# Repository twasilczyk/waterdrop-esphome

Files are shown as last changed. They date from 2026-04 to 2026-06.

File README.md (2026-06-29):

# waterdrop-esphome

Smarten Waterdrop RO systems: a plug-in Wi-Fi add-on board to integrate with Home Assistant, read hidden diagnostic parameters, and work around refrigerator line limitations.

See the story: [Hacking a water filter through a 7-segment display](docs/story.md).

> [!WARNING]
> Use at your own risk. This is not a certified retail product, but an open-source hacking hobby project.

## Features

- Reads sensors exposed by original RO unit
  - Water TDS level
  - Individual filter state: total and remaining life plus derivative sensors (life percentage, filter health warning)
  - Pump state (idle, active, flushing)
  - Error codes
  - Ambient air temperature
  - Last filter change time
  - [Potentially more](docs/reverse-engineering.md), as about fourteen 16-bit fields are still not reverse-engineered
- Simulates faucet handle position (see [Refrigerator line workaround](#refrigerator-line-workaround))
- Switchable power supply to the main RO unit
- Emergency water shutoff with external latching solenoid valve

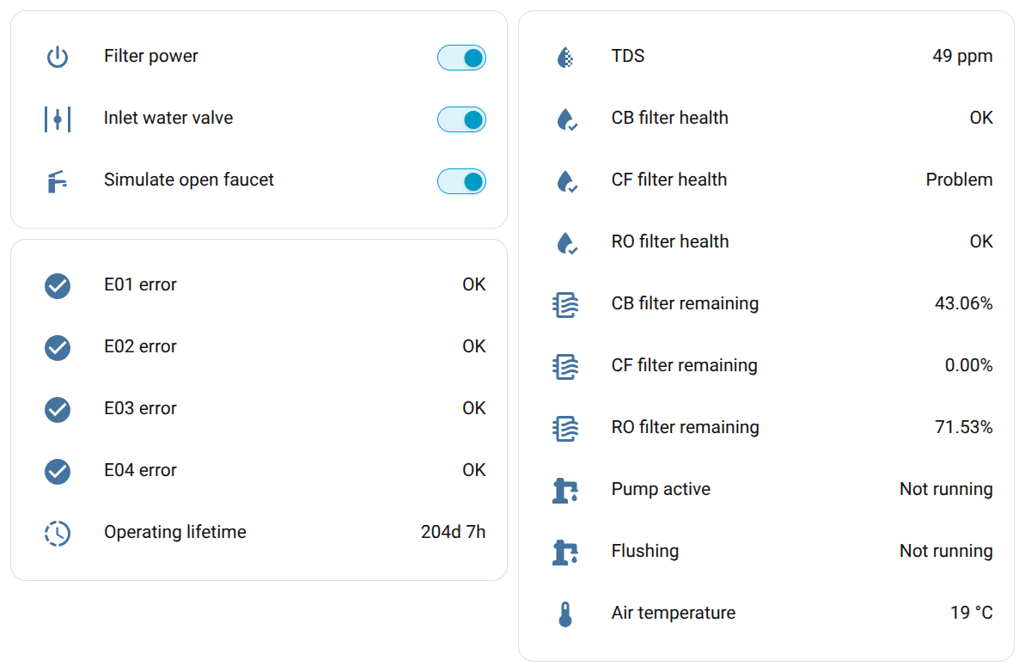
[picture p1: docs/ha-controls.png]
Screenshot of Home Assistant dashboard with controls and sensors


### Refrigerator line workaround

Waterdrop RO water filter systems don't play particularly well with refrigerator water lines. After dispensing water from the refrigerator, the RO unit tends to switch to an erratic flush mode: briefly flushing every 5 minutes. This continues until water is dispensed from the original Waterdrop smart faucet.

The simulated faucet handle feature works around this issue. If the RO unit performs this flush attempt while the faucet is reported open, it will start a proper flush cycle and switch back to the regular 12-hour flushing interval.

## Installing firmware

### ESPHome Builder

Best for long-term maintenance.

1. Define the following secrets (ESPHome Device Builder 🡒 three-dot menu 🡒 Secrets):
   - common_api_encryption_key
   - ota_password
   - wifi_ssid
   - wifi_password
2. Create device 🡒 Advanced set up options 🡒 Empty Configuration; paste the following:
   ```
   substitutions:
     branch: stable

   packages:
     waterdrop-esphome:
       url: https://github.com/twasilczyk/waterdrop-esphome
       ref: ${branch}
       files:
         - firmware/builder-package.yaml
   ```
3. Install over USB at first, then you can switch to OTA
4. If installing for the first time, don't forget to enable power to the RO system - it controlls both power supply and serial communication (with faucet as well as the main unit)

### Local environment

Best for development (from terminal or VSCode).

1. Set up ESPHome through the [pip method](https://esphome.io/guides/installing_esphome/#pip)
2. `cd path/to/repo`
3. `ln -s "$HOME/path/to/your/esphome-venv" .venv`
4. Create `secrets.yaml` one directory up from your repo root:
   ```
   wifi_ssid: "YourWiFi"
   wifi_password: "..."
   ota_password: "..."
   common_api_encryption_key: "..."
   ```

Then, you can build from terminal:
```
cd firmware
esphome run waterdrop-esphome.yaml
```

Or from VSCode:
1. Ctrl+Shift+P
2. `Tasks: Run Task`
3. `ESPHome: Run without debugging`

## Electronics

### Bill of materials

| Ref | Qty | Value | Product | Total cost [$] | Optional |
| --- | --- | --- | --- | --- | --- |
| C1  | 1 | 100µF/50V | 50YXJ100M8X11.5  | 0.43 | |
| C2  | 1 | 220µF/16V | 25YXJ220M6.3X11  | 0.31 | |
| C3  | 1 | 22nF | CL21B223KBANFNC  | 0.10 | |
| C4  | 1 | 100nF | CL21B104KBCNNNC  | 0.10 | |
| D1  | 1 | SMAJ30A | SMAJ30A | 0.22 | |
| D2  | 1 | B360A | B360A-13-F | 0.51 | |
| D3  | 1 | 1N4148 | 1N4148W-7-F | 0.17 | Yes (relay) |
| F1  | 1 | 500mA | 0PTF0078P + 0217.500MXP | 1.35 <!-- 0.78 + 0.57 --> | |
| J1  | 1 | DC5525 m  | PJ-002B | 0.66 | |
| J2  | 1 | DC5525 f  | 10-02950 | 3.17 | Yes (relay) |
| J3  | 1 | | Waterdrop | 0.00 | |
| J4  | 1 | 5pin 2.54 | PH1RB-05-UA | 0.15 | |
| J5  | 1 | 2pin 2.54 | PH1RB-02-UA | 0.10 | Yes (valve) |
| K1  | 1 | SPDT 24V  | G5LE-1-E DC24 | 2.74 | Yes (relay) |
| L1  | 1 | 33µH | 12RS333C | 1.35 | |
| L2  | 1 | 1µH | MLZ2012A1R0WT000 | 0.10 | |
| Q1  | 1 | BC817 | BC817-40-7-F | 0.23 | Yes (relay) |
| R1  | 1 | 3.6k | 0805 | 0.10 | |
| R2  | 1 | 1.2k | 0805 | 0.10 | |
| R3,R11 | 2 | 10k | 0805 | 0.20 | R3 (relay) |
| R4  | 1 | 47k | 0805 | 0.10 | Yes (relay) |
| R5,R6,R9,R13 | 4 | 100k | 0805 | 0.40 | R13 (valve) |
| R7,R10,R12 | 3 | 51k  | 0805 | 0.30 | R12 (valve) |
| R14 | 1 | 1Ω | 0805 | 0.10 | Yes (valve) |
| U1  | 1 | LM2596DS-ADJ | LM2596DSADJG  | 2.34 | |
| U2  | 1 | ESP32-S3-Tiny | [ESP32-S3-Tiny-Kit](https://docs.waveshare.com/ESP32-S3-Tiny?variant=ESP32-S3-Tiny-Kit) | 11.99 | |
| U3  | 1 | 74AHCT125 | SN74AHCT125QDRQ1 | 0.70 | |
| U4  | 1 | TB67H450A | TB67H450AFNG | 0.85 | Yes (valve) |
| | 34  | | | 28.87 | 21.11 w/o |

### Inlet water valve

Inlet water valve is an emergency shutoff valve for inlet water in case other components of your smart home detected a leak. However, I haven't had much luck finding one exactly matching my requirements:
 - Latching/pulse/bistable, so it doesn't take constant load (if Normally Closed) or wouldn't unintentionally re-open water flow in case of power loss (if Normally Open).
 - 3/8" Push-Fit connection to match RO system tubing.
 - Ideally 24V, to directly accept RO power supply voltage.
 - Reasonably priced.

A close one is SDF-S209B-24V, priced at $3.65 - but requires two G1/2 to Push-Fit 3/8 adapters. **24V latching solenoids are the only supported type of external inlet valves.**

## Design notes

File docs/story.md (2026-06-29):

# Hacking a water filter through a 7-segment display

It's a catchy headline, but that's pretty much what happened: I took one of the most boring appliances in the kitchen and squeezed some interesting discoveries out of hacking it.

> [!TIP]
> If you happen to own a Waterdrop RO water filter system and want to smarten it and maybe do some reverse engineering, all you need is $25 worth of parts and basic soldering skills (or just ask a PCB fab for assembly). Everything you need to get started is in the [fully open-source GitHub project](https://github.com/twasilczyk/waterdrop-esphome).

When I ordered my Waterdrop G3P600, the first thing that caught my attention was a "smart faucet" with a 7-segment display, connected to the RO unit with a 4-pin connector. The practical reason to control it was that I wanted to install the system in the basement and still get information on my phone. But really, I needed to scratch that reverse-engineering itch and wanted to put that new somewhat professional-looking (read: not looking like Arduino) ESP32 module to some use. The first obstacle was an uncommon connector, but Waterdrop generously offers a 1-meter extension cord free of charge. That's enough for two connectors: one for the RO unit, the other for the faucet side for future pass-through support. Alternatively, one could simply cut the faucet's original cable and replace the original connector with a 5-pin dupont plug connected directly to the ESP32 board.

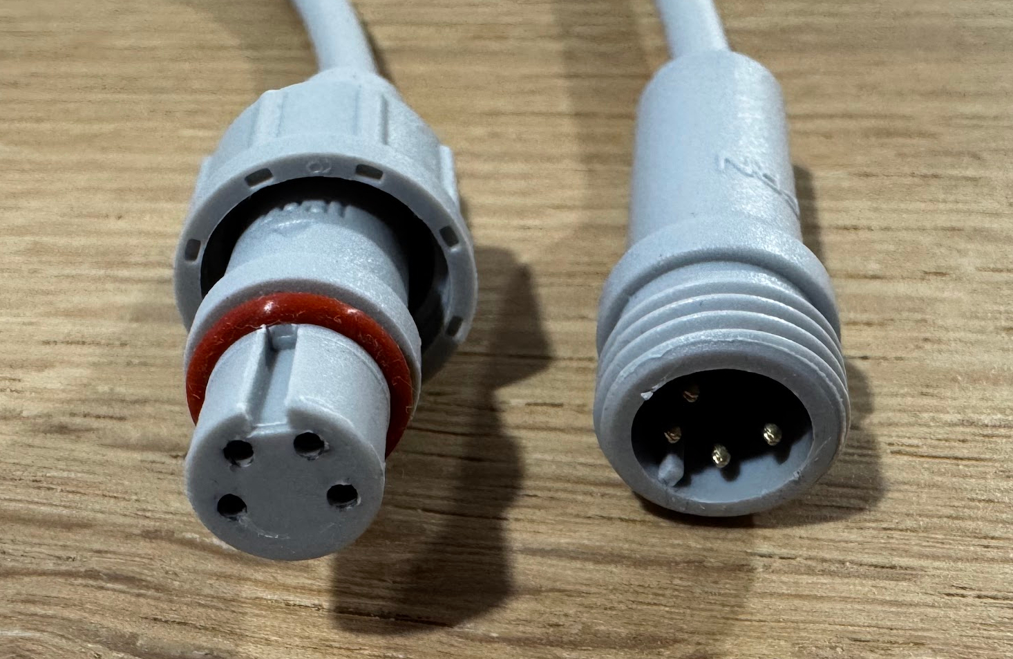
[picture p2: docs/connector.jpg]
Photo showing both ends of a 4-pin faucet connector
\
<sup>4-pin faucet connector.</sup>

After a few quick voltage measurements and dumping some transmissions with my trusty Saleae, the 4-pin connector turned out to have very straightforward characteristics: 5V power and ground, plus a 9600-baud serial connection. What I didn't measure, and what would bite me later, was the power supply I was planning to parasite from - it was 24V instead of the 12V I assumed. The protocol seemed simple, but not as simple as one could expect for controlling a few 7-segment digits and half a dozen extra LEDs: there were three different frames going out of the RO unit and one frame from the faucet. The first and last would always be there, while the middle one would only show up when the faucet was connected.

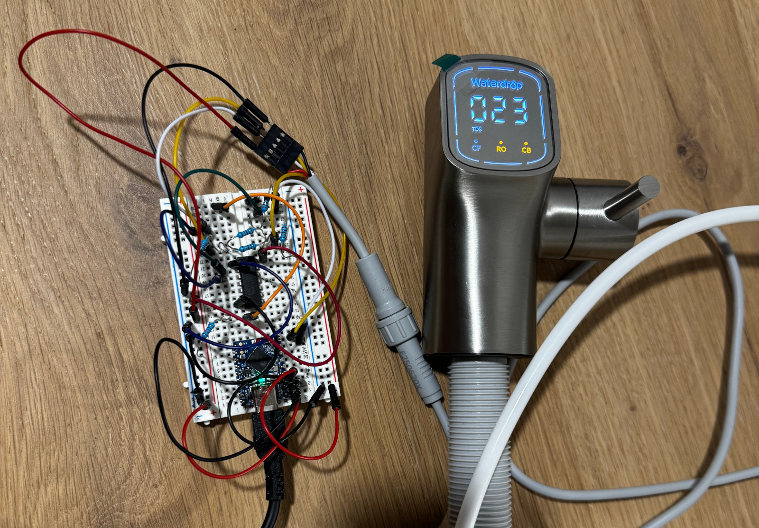
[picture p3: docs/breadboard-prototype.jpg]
Photo showing a messy breadboard prototype with smart faucet hooked up with jumper wires
\
<sup>Breadboard prototype.</sup>

One of the reasons I started this was to evaluate how useful AI would be for a hobby project - so the first task was to make something out of the protocol. I dumped the transmission from the logic analyzer and fed it into an AI chatbot. The thing immediately figured out the frame structure, quirky checksums, and request-response protocol. Then, using a breadboard prototype (big words for an ESP32 devboard plus a logic shifter), I asked AI again to replicate this protocol in ESPHome YAML - another hour or two saved, especially for throwaway test code.

The first phase of protocol reverse engineering was all about controlling the faucet display on my desk. Simply replaying frames recorded from the original transmission made it light up - as long as the faucet was in the "open" position. I was able to quickly find the bytes responsible for the 7-segment TDS (water quality) display and make it count up from 1 to 999. But [two bytes](https://github.com/twasilczyk/waterdrop-esphome/blob/637fe8d84ecb4e1f349285dedee15dd9a6db010c/firmware/components/waterdrop_serial/message.h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) can encode much larger values, can't they? Turned out that higher numbers are displayed as "F-codes" without the trailing two digits, where F10 represents TDS 1000 and F99 means 9900-9999. But this is not the full 16-bit range, is it? Indeed, the next 6 thousand values turned out to be a weird form of *hex*-coded-decimal (FA0 for 10000 up to 15999 for FF9). But how about even higher numbers? At this point, TDS of 16000 ppm would be worse than sewage (up to 1100 ppm) coming out of your drinking water faucet, closer to seawater (about 35000 ppm).

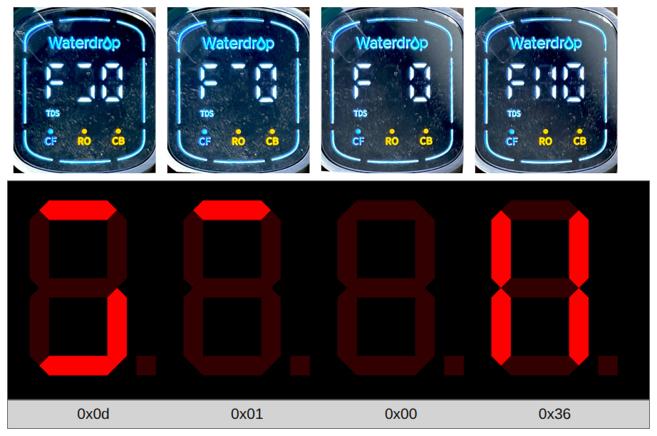
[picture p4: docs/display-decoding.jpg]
Collage of 7-segment display photos showing different F-codes, their representation in 7-segment decoder and corresponding hexadecimal values
\
<sup>*Garbage* display output for TDS values in the 33000-36000 ppm range.</sup>

Turns out, TDS values beyond 16000 show garbage glyphs. Or is it garbage? Driven by too much curiosity, I found online [7-segment display calculator](https://jasonacox.github.io/TM1637TinyDisplay/examples/7-segment-animator.html) to visually encode segment displays into numbers (used to drive a display's abcdefg pins). I was able to map out all possible segment combinations by setting all 65 different "thousand" values and painstakingly keying shapes into the online calculator and noting down the results. What I saw wasn't garbage - [it was the exact order](https://github.com/twasilczyk/waterdrop-esphome/blob/637fe8d84ecb4e1f349285dedee15dd9a6db010c/protocol/NOTES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) in which the faucet was requesting frames [I had seen in the live protocol before](https://github.com/twasilczyk/waterdrop-esphome/blob/637fe8d84ecb4e1f349285dedee15dd9a6db010c/firmware/components/waterdrop_serial_ro/waterdrop_serial_ro.cpp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)! Moreover, these numbers appeared again in some kind of registry with magic values, also showing [one more slot](https://github.com/twasilczyk/waterdrop-esphome/blob/637fe8d84ecb4e1f349285dedee15dd9a6db010c/protocol/NOTES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) number that didn't appear in the protocol at all. After all, it looks like the TDS display was using Flash or EEPROM as storage for decimal glyphs, not checking if the value being shown isn't out of the usual range - causing a typical [buffer overrun](reverse-engineering.md#buffer-overrun-in-the-faucet).

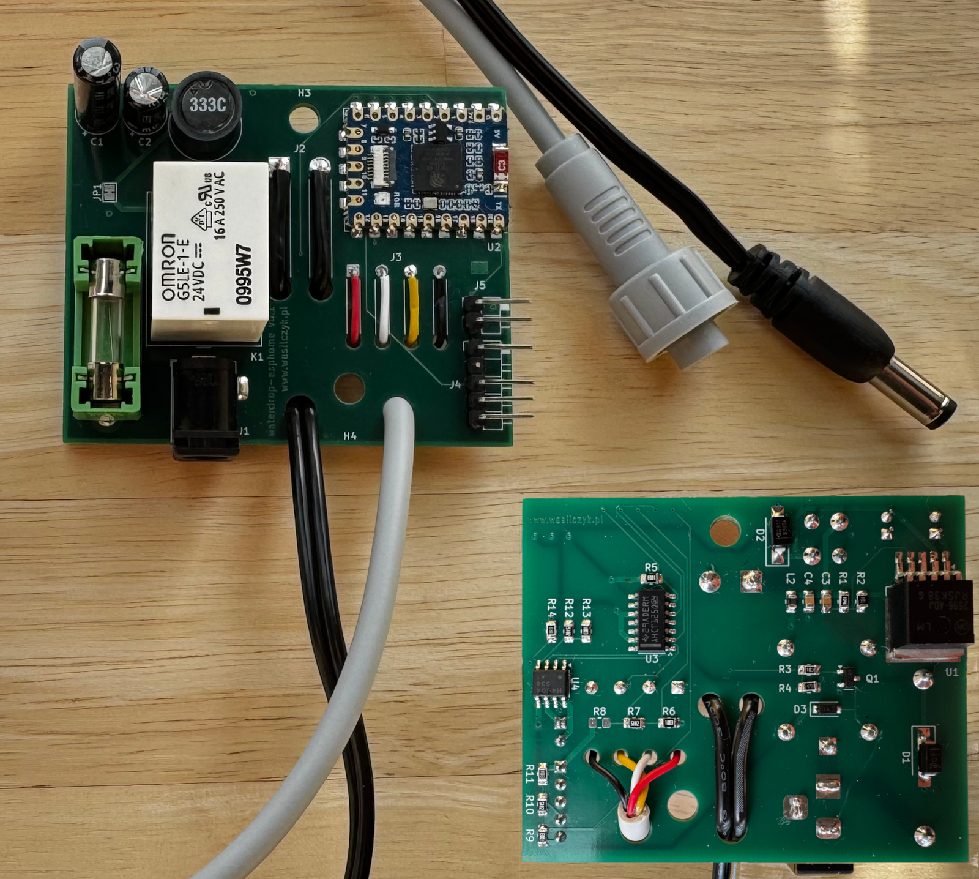
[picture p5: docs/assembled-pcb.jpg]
Photo showing front and back of assembled device PCB
\
<sup>Prototype with a few mistakes already fixed. See this [50V cap](https://www.digikey.com/en/products/detail/rubycon/50TXW100MEFC6-3X25/3563172) that had to fit in 6.3mm footprint?</sup>

It was time to verify all of these protocol assumptions with the other side - the RO unit. But replaying frames in YAML wouldn't cut it, since now we had to analyze the filter state. By that time my first PCB prototype had arrived from China, so I was able to loop back the simulated RO filter signal into the newly implemented faucet simulator. It worked on the first try! But don't be fooled - yes, while it took me 10 minutes to generate the first *fully working* iteration of the C++ implementation, it still took another couple evenings to refine this rather short code to my liking. I must say AI is very good at generic code and digging deep into framework documentation, but falls short when you want something very specific - like the protocol representation I made in [frame.h](../firmware/components/waterdrop_serial/frame.h) and [message.h](../firmware/components/waterdrop_serial/message.h).

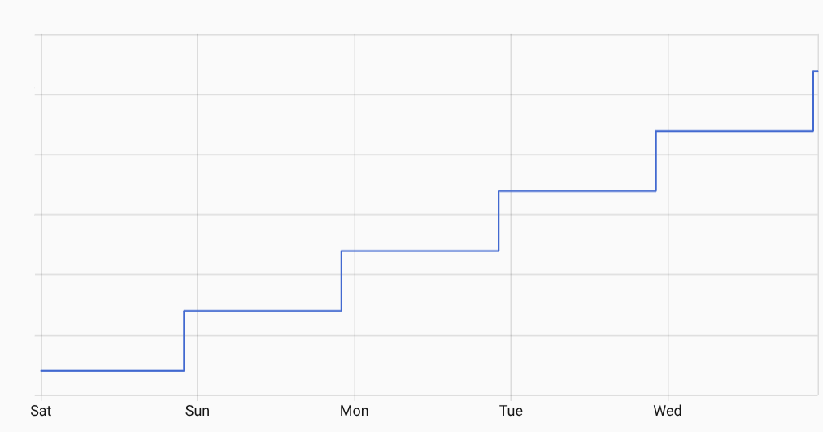
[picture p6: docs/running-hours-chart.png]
Screenshot of Home Assistant chart increasing steadily in steps
\
<sup>Unknown sensor increasing by 24 every 144<em>4.5</em> minutes.</sup>

Finally, I made a leap of faith and tried connecting the board to my RO unit. One blown fuse later (remember I forgot to measure the power supply?) I got it talking to me! Unfortunately, AI isn't magic and it wasn't able to figure out what the filter unit was saying, but Home Assistant came to the rescue. My trick was to represent all magic fields as integer sensors and let HA draw history graphs of their values. With a couple days' worth of graphs and some back-and-forth checking my findings on the faucet display, I was able to find some expected readings: individual filter remaining health, total filter life (no idea what the unit is though), kinda when it runs the pump, and even something that looks like water temperature. One sensor caught my attention: it was changing once a day. And every day it goes up by a value of 24. Right! It's the total running hours for the filter since I bought it. But wait... it doesn't increase every 24 hours, but every [24 hours and almost 5 minutes](https://github.com/twasilczyk/waterdrop-esphome/blob/637fe8d84ecb4e1f349285dedee15dd9a6db010c/firmware/components/waterdrop_serial/message.h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)!

What I later discovered was that the value represented time from last (any) filter replacement - likely for service use. The drift was somewhat stable, but still varied by tens of seconds, and that it would jump to massive values (hours) if I reset the system during a given day. This points to two engineering compromises likely made here: the internal clock uses a (free) internal oscillator, accepting a minor time drift, and EEPROM is written only once a day to preserve write cycles, accepting another statistically minor time error. What's notable is that this clock would roll over after about 7 and a half years - a bug waiting to happen for one gross user!

Screenshot of Home Assistant controls and sensors such as TDS, CB filter state and switches\
<sup>Reverse-engineered properties of the system.</sup>

Eventually, I decided I had already spent more time on this project than anticipated, but also achieved more than expected. There's still [tons to discover here](reverse-engineering.md) - including low-hanging fruit like figuring out the exact meaning of the filter status fields, mapping some analog sensors (it would probably help to open the RO unit and see what sensors are there), and hooking it to more advanced units with more filters and faucet buttons. If you want to dip your fingers into this fun puzzle set, you just need to order a PCB from your favorite cheap fab (I paid a total of $6.19 for mine) and $18-$25 worth of components from your favorite supplier to mount on it.

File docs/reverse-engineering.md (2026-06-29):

# Reverse engineering notes

Reverse-engineered protocol details are described in [message.h](../firmware/components/waterdrop_serial/message.h), but this document collects observations about partially reverse engineered values.

## MagicSensor1

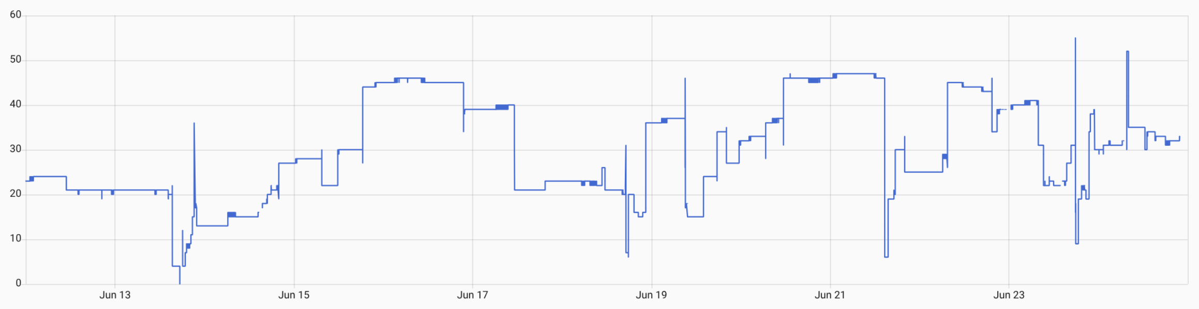
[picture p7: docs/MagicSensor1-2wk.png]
HA-generated graph of MagicSensor1 data (2 weeks log)
\
<sup>MagicSensor1's 2-week log.</sup>

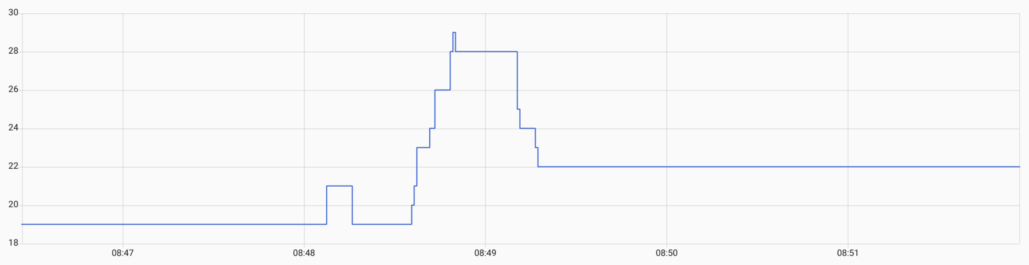
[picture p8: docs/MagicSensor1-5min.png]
HA-generated graph of MagicSensor1 data (5 minutes log)
\
<sup>MagicSensor1's 5-minute close up.</sup>

Erratically updating value - clearly analog as shown in the close-up.
 - Normal range 4-46, but with occasional 0 and observed values as high as 53 (during mild winter).
 - Seems to update when dispensing water.
 - Looked like water pressure, but couldn't confirm it with measurements at nearby faucet.

## MagicCounter1

 - Increases by 10 every ~5min 22s after water flow problems (ejected filter, closed valve), but only 5 times.
 - After it rises 5 times during water flow problem, it stops and E03 error gets activated.
 - Some variants (`magicCounter1a` and `magicCounter1b`) drop when their respective filter is reset, others (`magicCounter1c` and `magicCounter1d`) drop when *any* filter gets reset.

## System state

System state events are spread between 3 fields:
 - `MessageC2::state`
 - `MessageC5Slot04::unknown1`
 - `MessageC5Slot04::unknown2`

I wasn't however able to precisely pin down all system operations to these bits.

### Observations

#### Idle
 - C2=FF, C5u1=FF, C5u2=F1

#### Filling glass with water (without pressure tank):
 - C5u2 doesn't change at all
 - First 3 seconds: C2 oscillates between F1 and FF with 650ms period
 - Then C5u1 joins, oscillating between F1 and FF with 2.5s period
 - However, when I cleared out "activity every 5 minutes", both started at the same time,
   oscillating slow once and then C2 continued fast and C5u1 slow.

#### Filling pitcher or glass with water (with pressure tank):
 - C5u2 doesn't change at all
 - Both C2 and C5u1 oscillate together (at the same time) between F1 and FF with 8s cycle

#### Activity every 5 minutes (with or without pressure tank):
 - C2 goes FF -> F7 -> F1 -> FF very quickly (unmeasurable in HA)
 - Variant A: C5u1/2 doesn't change
 - Variant B: C5u1/2 change to F7 for 2x the time C2 was not in idle (starting together with C2)
 - Variant C: C5u1 changes to F1 for 2x the time C2 was not in idle, C5u2 doesn't change
 - Variants change periodically (cycle is 5 minutes):
   - Variant A runs for 2 cycles after water use or 9 cycles (but sometimes 6, first time after
     water use) after Variant C
   - Variant B runs for 3 cycles after Variant A
   - Variant C runs for 5 cycles after Variant B (but sometimes 8, first time after water use)
 - I was able to clear this by claiming "the faucet is open", so there was no activity for the
   next 8 hours until the next use. But switching to this state doesn't clear it alone - it has
   to happen right before the 5-minute activity. Then, it triggers pump for 1 minute.

## Air temperature:
It's present in 4 fields that looks the same. But then why is it twice in `MessageC5Slot05`?

## Other slots

Original faucet requests slots in the following order:
0x0D, 0x01, 0x0E, 0x0F, 0x03, 0x02.

RO system responds to other slots though:
 - 0x05: `00 00 00 xx 00 00 00 00` with often changing xx byte
 - 0x07: constant `00 00 00 00 00 00 00 00`
 - 0x10: constant `00 00 00 00 00 00 66 22`
 - all others: `01 00 00 CA xx xx xx yy`
   - xx are the same as in last transmitted C5 frame payload
   - yy is that frame's checksum

## Buffer overrun in the faucet

TDS display is transmitted as 16-bit unsigned integer, but only values 1-999 are displayed
directly. Values 03E8 (1000) to 270F (9999) are displayed without trailing 2 digits as F-codes
(e.g. 1000 as F10, 2500 as F25, 9999 as F99). Values for the next 6 thousands are using
hexadecimal digits for the first digit only (e.g. 10000 as FA0, 11500 as FB5, 15999 as FF9).
Values between 16000 and 65535 span beyond the lookup table, allowing to dump the next 49 bytes of
EEPROM/Flash (50 bytes including the trailing padding null byte of 7-segment glyphs table).

Useful tool to encode 7-segment display to bytes:
https://jasonacox.github.io/TM1637TinyDisplay/examples/7-segment-animator.html

Dumped memory layout (please note MSB is unknown due to missing dp segment in the display):
```
// Regular glyphs table (starting with 1 through F, nul terminated)
06 5b 4f 66
6d 7d 07 7f
6f 77 7c 39
5e 79 71 00

// Registers lookup table
01 01 00 26 (or A6)
02 01 00 2e (or AE)
03 01 00 53 (or D3)
07 01 00 5b (or DB)
0d 01 00 36 (or B6)
0e 01 00 3e (or BE)
0f 01 00 46 (or C6)

# Lookup table for slot numbers to request
0d 01 0e 0f
03 02

# Unused (likely FF, not 7F).
      7f 7f
7f 7f 7f 7f
7f 7f 7f 7f
7f 7f 7f 7f
7f
```

For registers lookup table, the first byte is slot number (same as in the lookup table) and last byte is value with unknown MSB. It's unclear if this is Lookup table (constant in Flash) or configuration (modifiable in EEPROM).

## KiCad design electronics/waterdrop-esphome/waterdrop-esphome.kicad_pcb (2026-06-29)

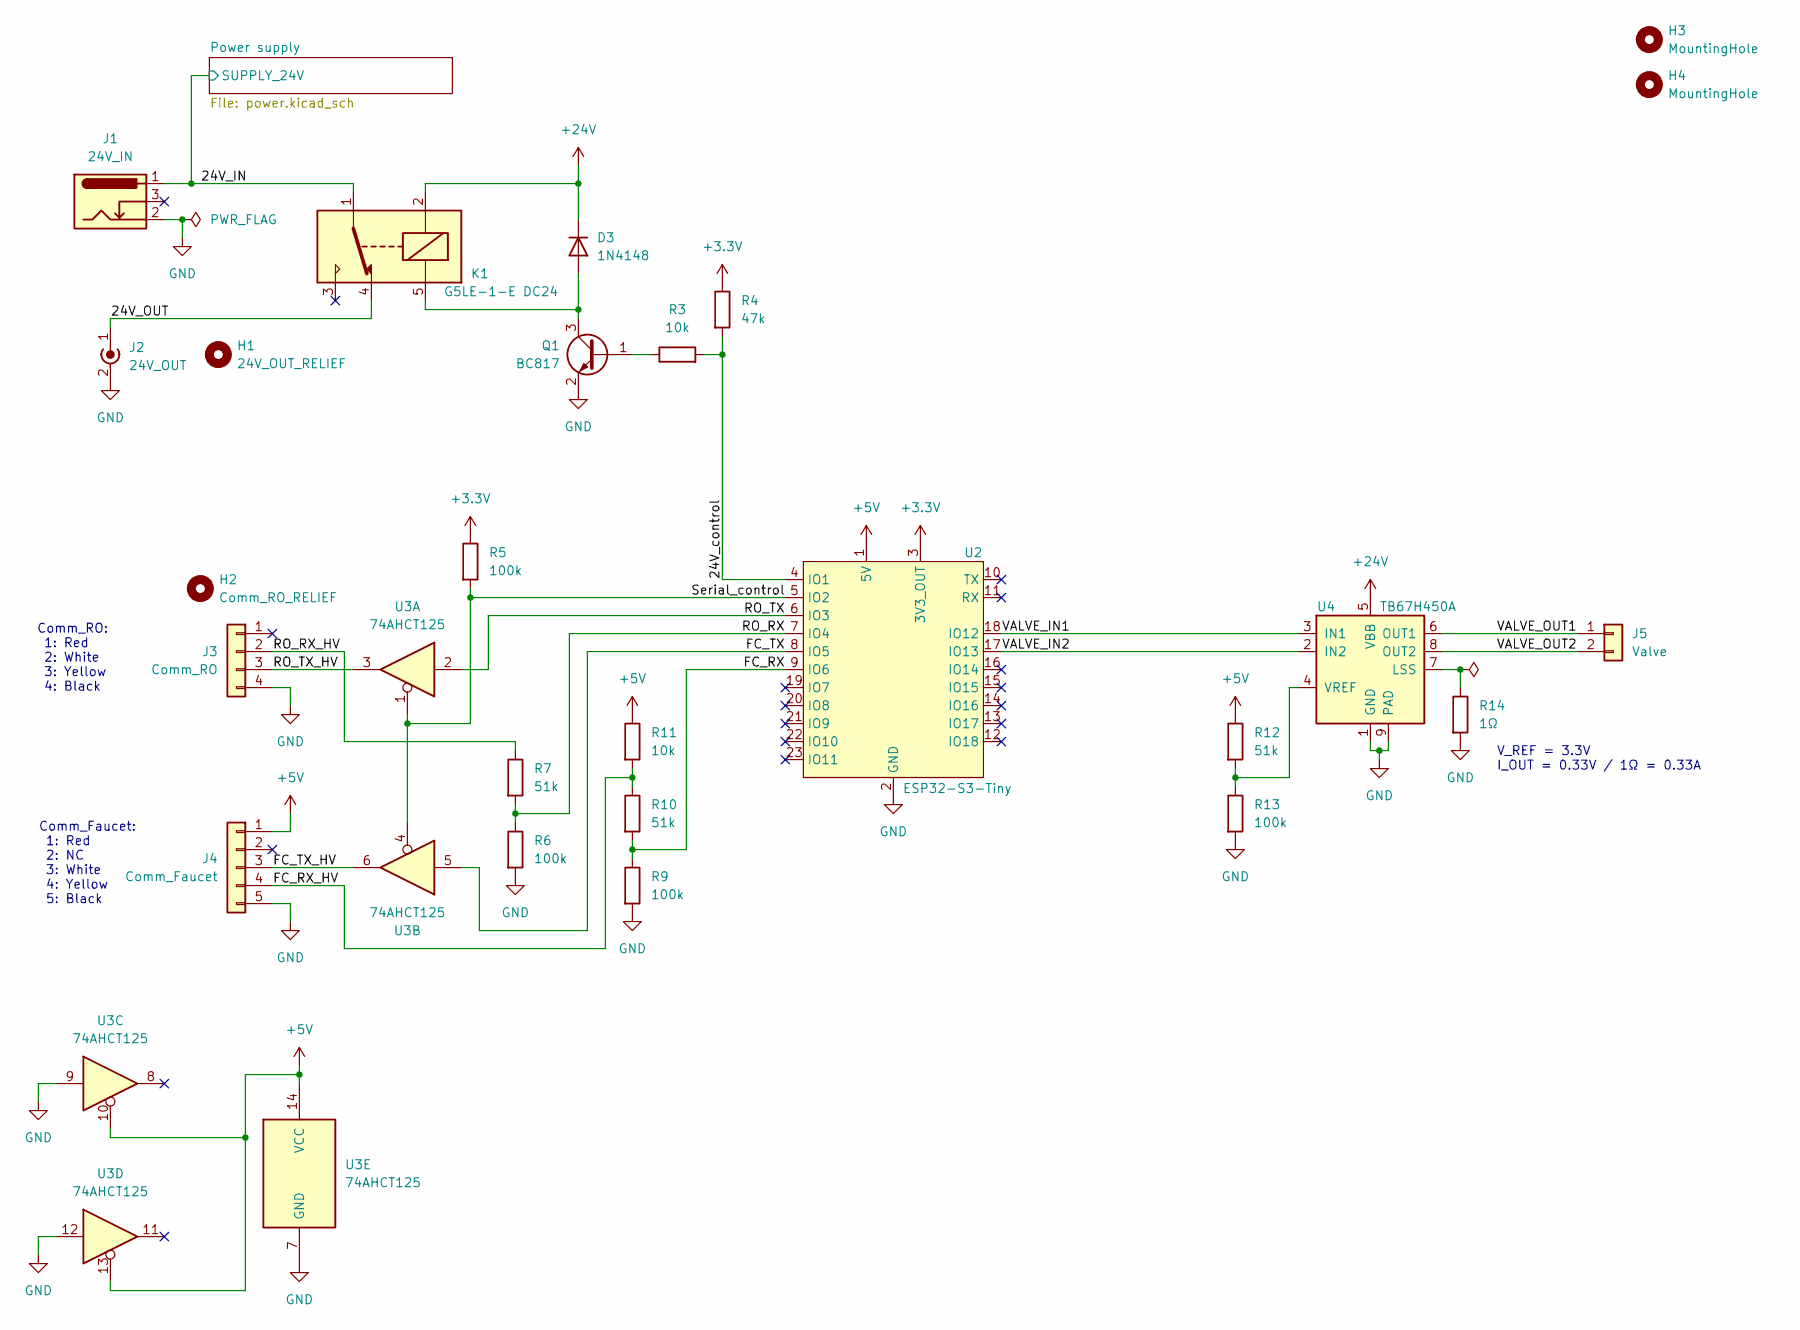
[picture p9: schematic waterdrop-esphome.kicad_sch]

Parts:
D3: 1N4148; D_SOD-123_Handsoldering
H1: 24V_OUT_RELIEF; MountingHole_4.3mm
H2: Comm_RO_RELIEF; MountingHole_4.3mm
H3, H4: MountingHole; MountingHole_3.2mm_M3
J1: 24V_IN; BarrelJack_Horizontal
J2: 24V_OUT; SolderWire-1.5sqmm_1x02_P6mm_D1.7mm_OD3mm_Relief
J3: Comm_RO; SolderWire-0.25sqmm_1x04_P4.2mm_D0.65mm_OD1.7mm_Relief
J4: Comm_Faucet; PinHeader_1x05_P2.54mm_Horizontal
J5: Valve; PinHeader_1x02_P2.54mm_Horizontal
K1: G5LE-1-E DC24; Relay_SPDT_Omron-G5LE-1
Q1: BC817; SOT-23_Handsoldering
R3, R11: 10k; R_0805_2012Metric_Pad1.20x1.40mm_HandSolder
R4: 47k; R_0805_2012Metric_Pad1.20x1.40mm_HandSolder
R5, R6, R9, R13: 100k; R_0805_2012Metric_Pad1.20x1.40mm_HandSolder
R7, R10, R12: 51k; R_0805_2012Metric_Pad1.20x1.40mm_HandSolder
R14: 1Ω; R_0805_2012Metric_Pad1.20x1.40mm_HandSolder
U2: ESP32-S3-Tiny; ESP32-S3-TINY-SMD
U3: 74AHCT125; SOIC-14_3.9x8.7mm_P1.27mm
U4: TB67H450A; SOIC-8-1EP_3.9x4.9mm_P1.27mm_EP2.29x3mm_ThermalVias

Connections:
+3.3V: R4.1, R5.1, U2.3 (3V3_OUT)
+5V: J4.1, R11.1, R12.1, U2.1 (5V), U3.10, U3.13, U3.14 (VCC); also elsewhere on the board
+24V: D3.1 (K), K1.2, U4.5 (VBB); also elsewhere on the board
/24V_IN: J1.1, K1.1; also elsewhere on the board
/24V_OUT: J2.1 (In), K1.4
/24V_control: R3.2, R4.2, U2.4 (IO1)
/FC_RX: R9.1, R10.2, U2.9 (IO6)
/FC_RX_HV: J4.4, R10.1, R11.2
/FC_TX: U2.8 (IO5), U3.5
/FC_TX_HV: J4.3, U3.6
/RO_RX: R6.1, R7.2, U2.7 (IO4)
/RO_RX_HV: J3.2, R7.1
/RO_TX: U2.6 (IO3), U3.2
/RO_TX_HV: J3.3, U3.3
/Serial_control: R5.2, U2.5 (IO2), U3.1, U3.4
/VALVE_IN1: U2.18 (IO12), U4.3 (IN1)
/VALVE_IN2: U2.17 (IO13), U4.2 (IN2)
/VALVE_OUT1: J5.1, U4.6 (OUT1)
/VALVE_OUT2: J5.2, U4.8 (OUT2)
GND: J1.2, J2.2 (Ext), J3.4, J4.5, Q1.2 (E), R6.2, R9.2, R13.2, R14.2, U2.2 (GND), U3.7 (GND), U3.9, U3.12, U4.1 (GND), U4.9 (PAD); also elsewhere on the board
unnamed: D3.2 (A), K1.5, Q1.3 (C)
unnamed: Q1.1 (B), R3.1
unnamed: R14.1, U4.7 (LSS)
unnamed: R12.2, R13.1, U4.4 (VREF)

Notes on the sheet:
Comm_Faucet: 1: Red 2: NC 3: White 4: Yellow 5: Black
Comm_RO: 1: Red 2: White 3: Yellow 4: Black
V_REF = 3.3V I_OUT = 0.33V / 1Ω = 0.33A

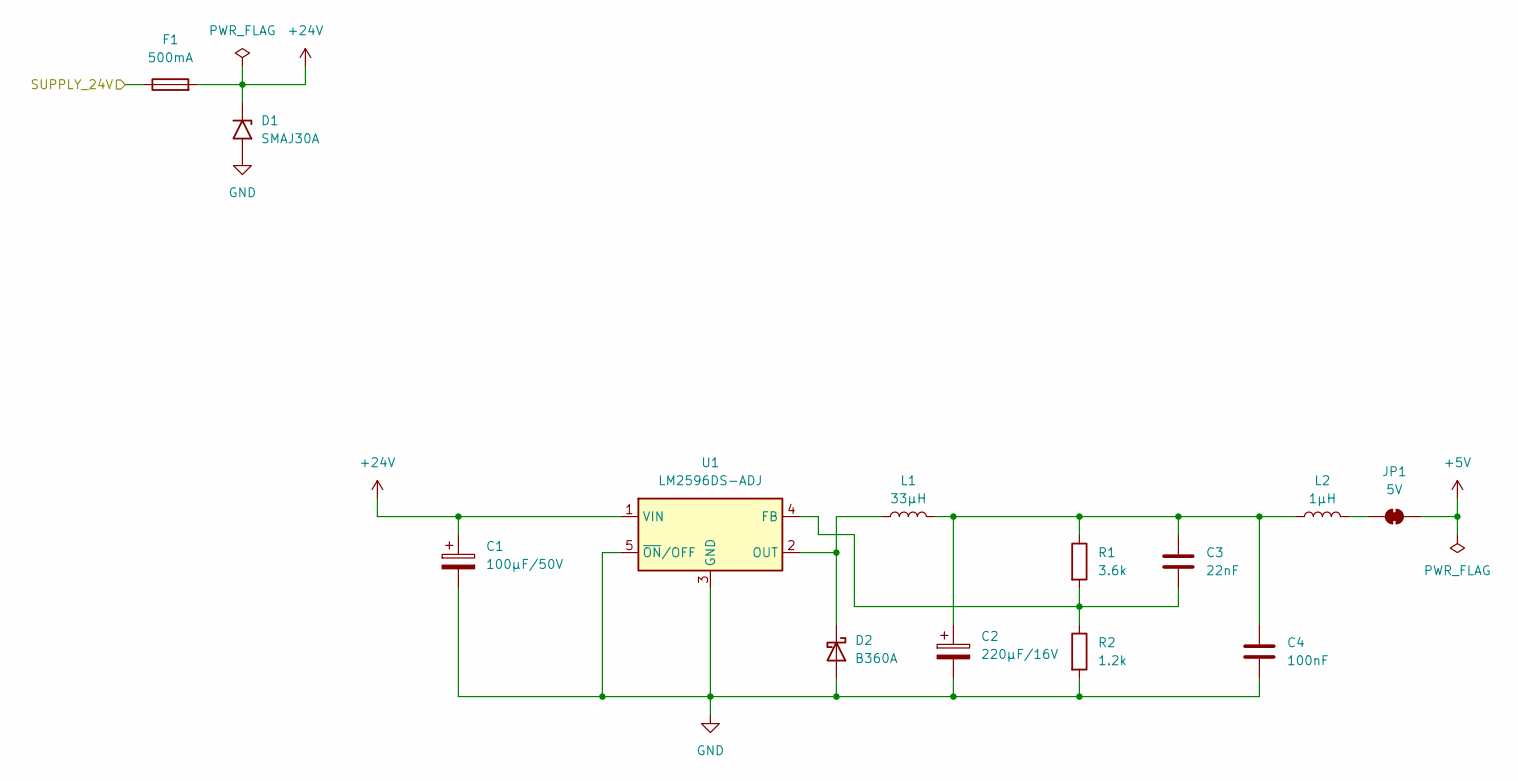
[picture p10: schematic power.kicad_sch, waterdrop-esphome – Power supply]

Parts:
C1: 100µF/50V; CP_Radial_D8.0mm_P3.50mm
C2: 220µF/16V; CP_Radial_D6.3mm_P2.50mm
C3: 22nF; C_0805_2012Metric_Pad1.18x1.45mm_HandSolder
C4: 100nF; C_0805_2012Metric_Pad1.18x1.45mm_HandSolder
D1: SMAJ30A; D_SMA_Handsoldering
D2: B360A; D_SMA_Handsoldering
F1: 500mA; Fuseholder_Cylinder-5x20mm_Stelvio-Kontek_PTF78_Horizontal_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
JP1: 5V; SolderJumper-2_P1.3mm_Bridged_Pad1.0x1.5mm
L1: 33µH; L_Radial_D10.5mm_P4.00x5.00mm_Murata_1200RS
L2: 1µH; L_0805_2012Metric_Pad1.15x1.40mm_HandSolder
R1: 3.6k; R_0805_2012Metric_Pad1.20x1.40mm_HandSolder
R2: 1.2k; R_0805_2012Metric_Pad1.20x1.40mm_HandSolder
U1: LM2596DS-ADJ; TO-263-5_TabPin3

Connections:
+5V: JP1.2 (B); also elsewhere on the board
+24V: C1.1, D1.1 (A1), F1.2, U1.1 (VIN); also elsewhere on the board
/24V_IN: F1.1; also elsewhere on the board
GND: C1.2, C2.2, C4.2, D1.2 (A2), D2.2 (A), R2.2, U1.3 (GND), U1.5 (~ON/OFF); also elsewhere on the board
unnamed: C2.1, C3.1, C4.1, L1.2, L2.1, R1.1
unnamed: D2.1 (K), L1.1, U1.2 (OUT)
unnamed: JP1.1 (A), L2.2
unnamed: C3.2, R1.2, R2.1, U1.4 (FB)

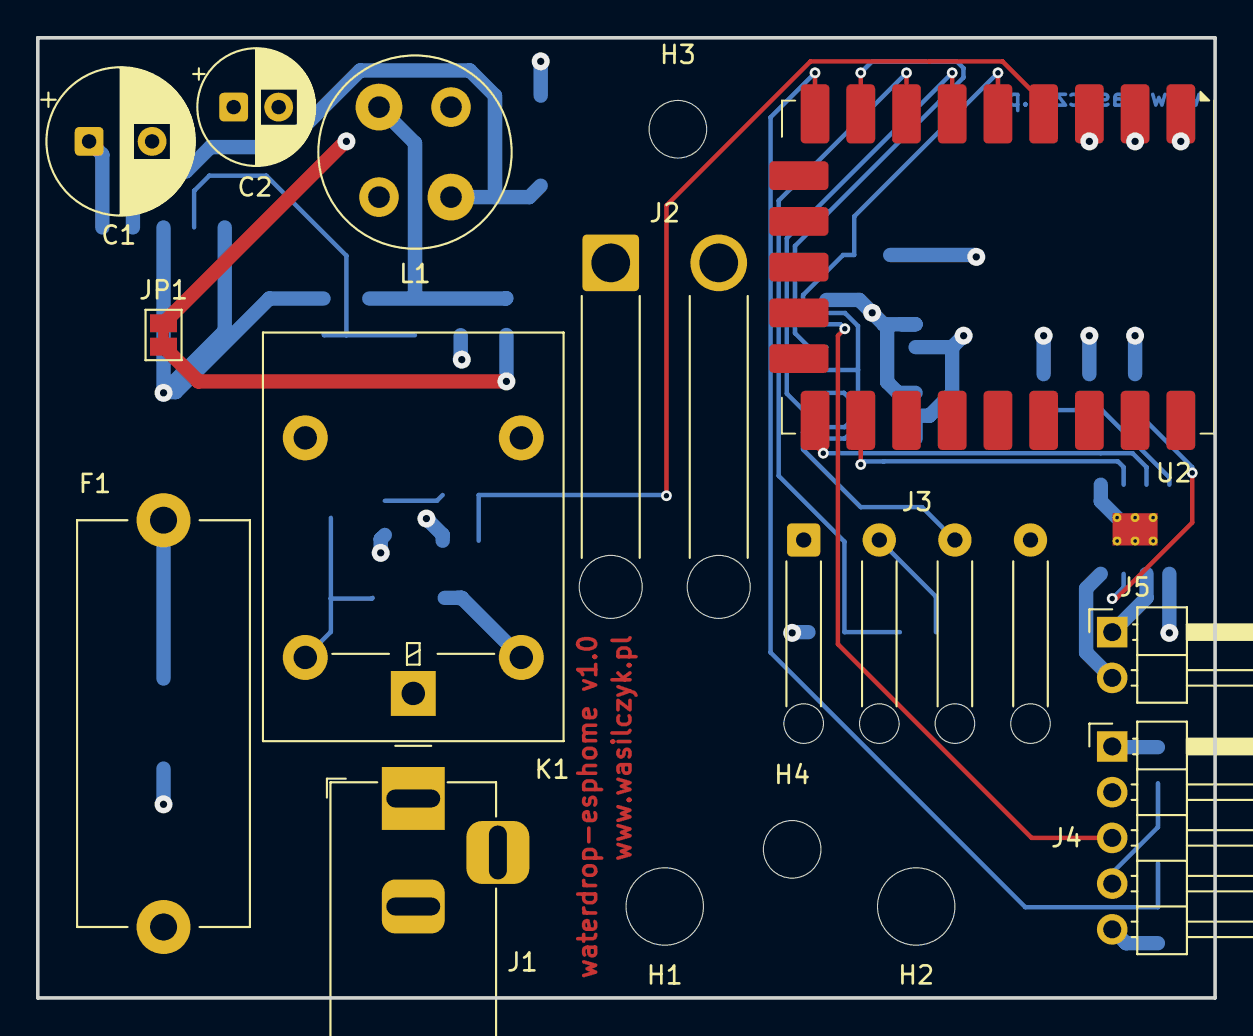
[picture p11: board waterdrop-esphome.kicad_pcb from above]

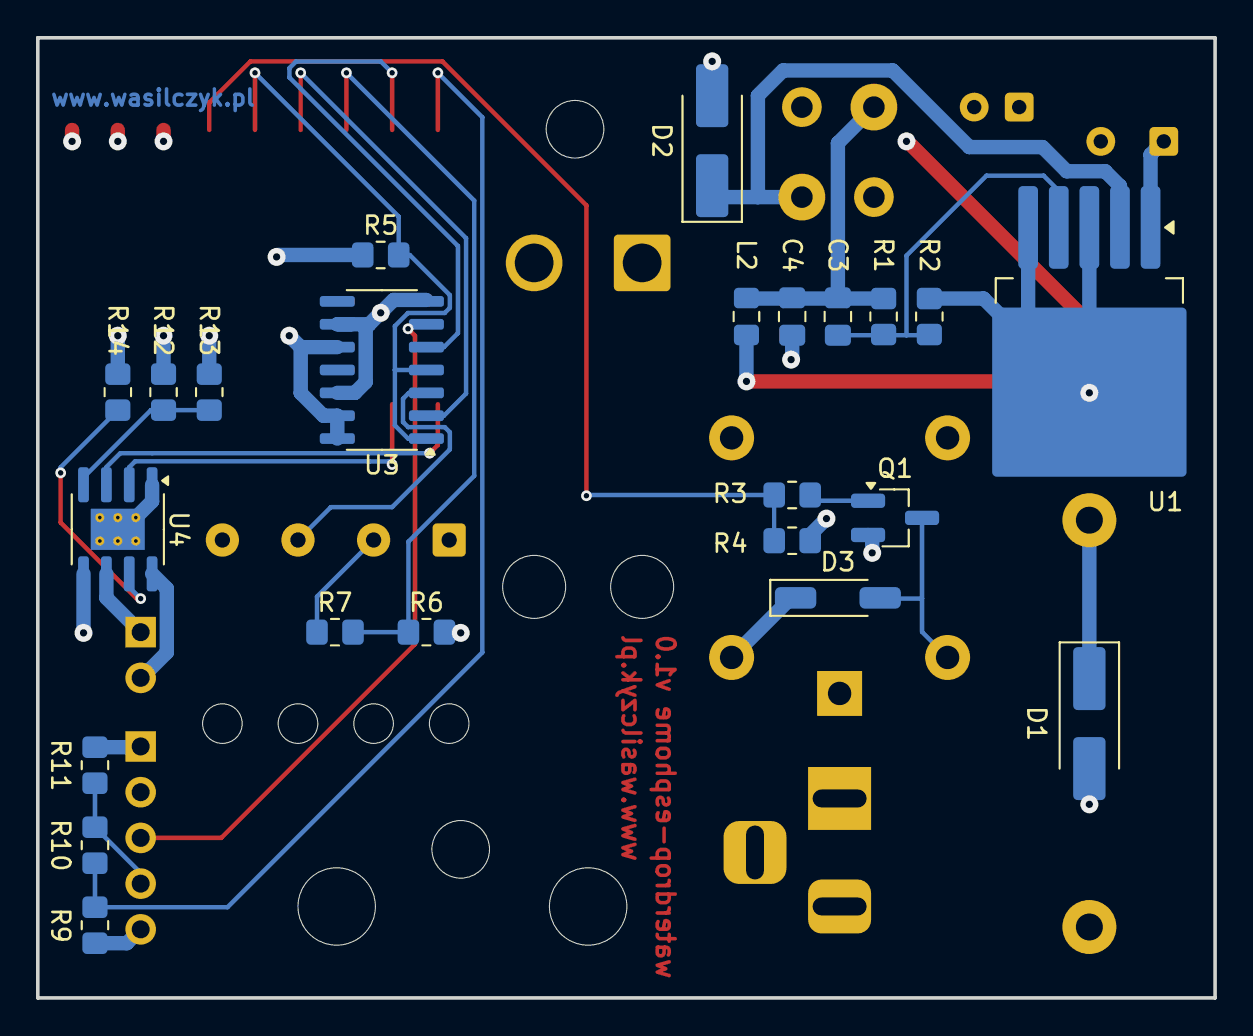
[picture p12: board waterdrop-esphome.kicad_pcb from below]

Board: 4 copper layers, 65.4 x 53.3 mm, 39 parts (23 on the bottom side), 28 nets.

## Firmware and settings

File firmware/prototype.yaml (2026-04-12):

esphome:
  name: prototype
  friendly_name: prototype
  includes:
    - helpers.h
  on_boot:
    - priority: 10
      then:
        - light.turn_on:
            id: status_led
            brightness: 20%
            red: 100%
            green: 0%
            blue: 0%
    - priority: 1000
      then:
        - delay: 10ms
        - light.turn_on:
            id: status_led
            brightness: 20%
            red: 100%
            green: 60%
            blue: 0%


esp32:
  board: esp32-s3-devkitc-1
  framework:
    type: esp-idf

logger:
  logs:
    script: WARN
    text_sensor: WARN

api:
  encryption:
    key: !secret common_api_encryption_key

ota:
  - platform: esphome
    password: !secret ota_password

wifi:
  ssid: !secret wifi_ssid
  password: !secret wifi_password
  on_connect:
    - delay: 100ms
    - light.turn_on:
        id: status_led
        red: 0%
        green: 100%
        blue: 0%
        brightness: 20%

switch:
  - platform: gpio
    name: "Filter power"
    pin: GPIO1
    id: filter_power
    inverted: true
    restore_mode: RESTORE_DEFAULT_OFF
  - platform: gpio
    name: "Serial enabled"
    pin: GPIO2
    id: serial_enabled
    inverted: true
    restore_mode: ALWAYS_ON
  - platform: gpio
    name: "ESP32 GPIO12 Switch"
    pin: GPIO12
    id: relay_12
  - platform: gpio
    name: "ESP32 GPIO13 Switch"
    pin: GPIO13
    id: relay_13

script:
  - id: send_frame
    mode: queued
    parameters:
      command: uint8_t
      payload: std::vector<uint8_t>
    then:
      - lambda: |-
          auto checksum = [](const std::vector<uint8_t> &bytes) -> uint8_t {
            uint8_t s = 0;
            for (auto b : bytes) s += b;
            return s;
          };

          static std::vector<uint8_t> frame;
          frame.clear();
          frame.reserve(payload.size() + 5);

          frame.push_back(0xAA);
          frame.push_back(0x55);
          bool payload_checksum = false;
          if (command == 0xC2 || command == 0x22) payload_checksum = true;

          uint8_t len = payload.size() + 5 + (payload_checksum ? 1 : 0);
          frame.push_back(len);
          frame.push_back(command);

          frame.insert(frame.end(), payload.begin(), payload.end());

          uint8_t frame_checksum = checksum(frame);
          if (payload_checksum) {
            uint8_t payload_checksum = checksum(payload);
            if (command == 0x22) payload_checksum -= payload[0];
            frame.push_back(payload_checksum);
          }
          frame.push_back(frame_checksum);

          id(uart_bus).write_array(frame.data(), frame.size());

  - id: send_message
    mode: queued
    parameters:
      p22: std::vector<uint8_t>
      pC5: std::vector<uint8_t>

    then:
      - script.execute:
          id: send_frame
          command: 0xC2
                                      # STATE:
                                      #  Boot: FF
                                      #  Screen on: F1, F7
                                      #  Flush: F3, F5, F6
                                      #  Screen off: all others

                                      # FLG2: no effect
                                      #  0x03 - regular
                                      #  0x01 - present during flush and boot

                                      # ERR:
                                      #  Display priority: E02 > E03 > E04 > E01
                                      #  0b00000100: E02
                                      #  0b00000001: E03
                                      #  0b00000010: E04
                                      #  0b10000000: E01

                                     # STATE   FLG   ERR
          payload: std::vector<uint8_t>{0xF1, 0x03, 0x00}
          #payload: !lambda |-
          #  return std::vector<uint8_t>{0xF1, counterLo(), 0x00};
          #payload: !lambda |-
          #  return std::vector<uint8_t>{bflip(0xF1, 0, id(hex_b1)), bflip(0x03, 1, id(hex_b1)), bflip(0x00, 2, id(hex_b1))};
      - delay: 40ms
      - script.execute:
          id: send_frame
          command: 0x22
          payload: !lambda |-
            return p22;
      - delay: 30ms
      - script.execute:
          id: send_frame
          command: 0xC5
          payload: !lambda |-
            return pC5;
      - delay: 40ms
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

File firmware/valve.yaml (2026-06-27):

substitutions:
  valve_pulse_duration: 10ms  # measured minimum for reliable operation: 2ms
  valve_cooldown: 0.5s

switch:
  - platform: gpio
    id: valve_in1
    pin: GPIO12
    restore_mode: ALWAYS_OFF
    interlock: [valve_in2]
  - platform: gpio
    id: valve_in2
    pin: GPIO13
    restore_mode: ALWAYS_OFF
    interlock: [valve_in1]

valve:
  - platform: template
    id: inlet_water_valve
    name: "Inlet water valve"
    device_class: water
    optimistic: true
    restore_mode: RESTORE_AND_CALL
    open_action:
      - script.execute:
          id: valve_pulse
          open: true
    close_action:
      - script.execute:
          id: valve_pulse
          open: false

script:
  - id: valve_pulse
    mode: restart
    parameters:
      open: bool
    then:
      - switch.turn_off: valve_in1
      - switch.turn_off: valve_in2
      - if:
          condition:
            lambda: 'return open;'
          then:
            - valve.template.publish:
                id: inlet_water_valve
                current_operation: OPENING
            - switch.turn_on: valve_in1
            - delay: ${valve_pulse_duration}
            - switch.turn_off: valve_in1
            - delay: ${valve_cooldown}
            - valve.template.publish:
                id: inlet_water_valve
                state: OPEN
                current_operation: IDLE
          else:
            - valve.template.publish:
                id: inlet_water_valve
                current_operation: CLOSING
            - switch.turn_on: valve_in2
            - delay: ${valve_pulse_duration}
            - switch.turn_off: valve_in2
            - delay: ${valve_cooldown}
            - valve.template.publish:
                id: inlet_water_valve
                state: CLOSED
                current_operation: IDLE

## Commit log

2025-12-15 Bring up prototype board
2026-01-03 Figured out filter usage
2026-01-09 Found filter life length config
2026-01-13 Initial schematics and pcb
    [power.kicad_sch, waterdrop-esphome.kicad_pcb, waterdrop-esphome.kicad_sch]
2026-01-13 ESP32-S3-Tiny doesn't have dual-purpose power pins, it requires 5V supply
    [power.kicad_sch, waterdrop-esphome.kicad_sch]
2026-03-12 Schematics for 12V circuit, describe serial level converter
    [waterdrop-esphome.kicad_sch]
2026-03-14 Schematics for serial communication
    [waterdrop-esphome.kicad_sch]
2026-03-14 Schematics for water valve
    [power.kicad_sch, waterdrop-esphome.kicad_sch]
2026-03-14 Schematics are ready for PCB layout
    [waterdrop-esphome.kicad_pcb, waterdrop-esphome.kicad_sch]
2026-03-15 PCB: lay out components
    [waterdrop-esphome.kicad_pcb, waterdrop-esphome.kicad_sch]
2026-03-27 PCB: trace and fix all DRC
    [power.kicad_sch, waterdrop-esphome.kicad_pcb]
2026-03-27 PCB: release settings
    [waterdrop-esphome.kicad_pcb]
2026-03-27 PCB: add signature
    [waterdrop-esphome.kicad_pcb]
2026-04-12 Firmware: update GPIO for 0.0.1 board
2026-04-13 Firmware: implement bi-stable valve
2026-04-21 Serial protocol: implement RO frames receiver
2026-04-25 Serial protocol: implement sending faucet frames
2026-04-26 Serial protocol: implement faucet frames receiver
2026-05-03 Serial protocol: ensure frame separation
2026-05-13 Serial protocol: better representation (big_uint16_t and Frame::as)
2026-05-14 Clean up old diagnostic sensors
2026-05-15 Expose serial data through sensors
2026-05-15 Add diagnostic byte sensors
2026-05-15 Tweak power and status icons
2026-05-16 Add unexpected frame sensor
2026-05-18 Serial protocol reverse engineering: update sensors for unknown values
2026-05-19 Discovered total hours powered on sensor
2026-05-21 Booting sensor was wrong, introduce pump active
2026-05-21 Avoid RO leeching power from serial when turned off
2026-05-31 Schematics: apply verified 0.1 fixes: - Bump version to 0.2 - Change mounting holes to M3 - 12 -> 24V input voltage: - C1: 16V -> 50V - D1: SMAJ13A -> SMAJ30A - D2: B220A -> B360A - K1: G5LE-1 -> G5L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
    [power.kicad_sch, waterdrop-esphome.kicad_sch]
2026-06-05 Remove R8: Serial RX pull-up from RO unit
    It's only necessary for faucet. Without this pull-up, this module already
    performs better than original faucet. Rising and falling edge comparison
    (+/- 10ns, except faucet rising edge):
    - 560ns with waterdrop-esphome (both RX and TX, both edges)
    - 620ns with original faucet (RO side, both edges)
    - 640ns with original faucet (faucet side, falling edge)
    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
    [waterdrop-esphome.kicad_sch]
2026-06-06 Filter remaining life can go negative
2026-06-07 Update footprints: D3 and Q1 hand soldering, C1 size
    [power.kicad_sch, waterdrop-esphome.kicad_sch]
2026-06-07 Document BOM
2026-06-07 Bump PCB version to 0.2
    [waterdrop-esphome.kicad_pcb]
2026-06-07 Update PCB to reflect schematic fixes
    [waterdrop-esphome.kicad_pcb]
2026-06-07 Fix PCB 0.1 nits
    [waterdrop-esphome.kicad_pcb]
2026-06-23 Discovered ambient air temperature
2026-06-23 Fix board strings
2026-06-24 Move faucet_open switch to config category
2026-06-24 Fix status LED priorities
2026-06-24 Don't drop valve open/close requests if they were made during cooldown period
2026-06-27 Inlet water valve: rename and document
2026-06-28 Raw byte -> Unknown sensor
2026-06-28 Protocol reverse engineering around filter replacement - MagicSensor1 - Expose all 4 temperature sensors - Note down state observations - Operating lifetime -> Last filter change - Correct article
    [message.h]
2026-06-29 Bump PCB version to 1.0 and firmware to 1.0.0
    [power.kicad_sch, waterdrop-esphome.kicad_pcb, waterdrop-esphome.kicad_sch]
